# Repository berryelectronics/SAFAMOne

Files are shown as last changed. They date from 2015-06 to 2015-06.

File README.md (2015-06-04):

# SAFAM One | WORK IN PROGRESS
##[FORUM THREAD WITH UPDATES ETC](http://goo.gl/dDuPXW)
##A Simple and Fast Microcontroller
###Based on the STM32F103 Microcontroller
####And the STM32duino Core, build up by Roger Clark, mrburnette, Bobc, victor_pv and many more

This Dev Board is build up around the [STM32F103RET6, a 32-BIT ARM Cortex M3 Microcontroller by STMicroelectronics](http://www.st.com/web/en/resource/technical/document/datasheet/CD00191185.pdf)

It offers a full pinout of the chip with functions, aswell as multiple pinouts of the Serial Communication Pins (SPI, I2C, I2S, UART) aswell as a direct Port for 2.4" Touchscreens and 2.8" Touchscreens.
Also it comes with a break-away Black Magic Probe Clone.

As this Project is still WIP, the schematic and the board will change. 
When the project is finished and you decide to make your own, you're doing it at your own risk. But if the Magic Black Smoke comes up, please report it to me, so i can fix it :)

~Straw/Berryelectronics

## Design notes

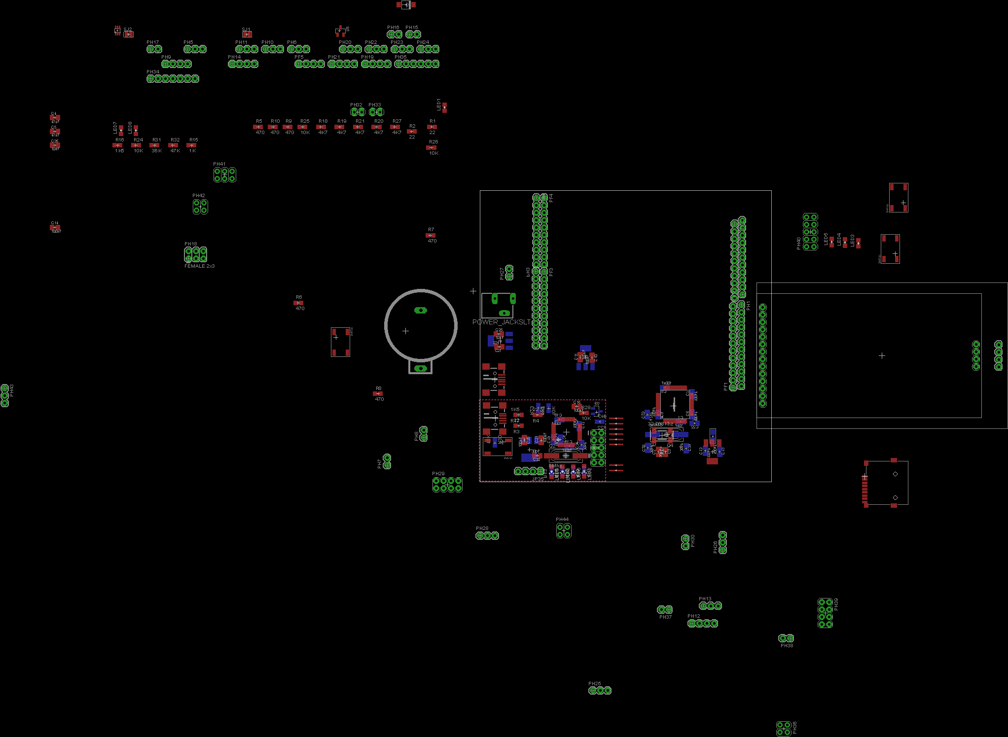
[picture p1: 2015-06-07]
Board_Design.png

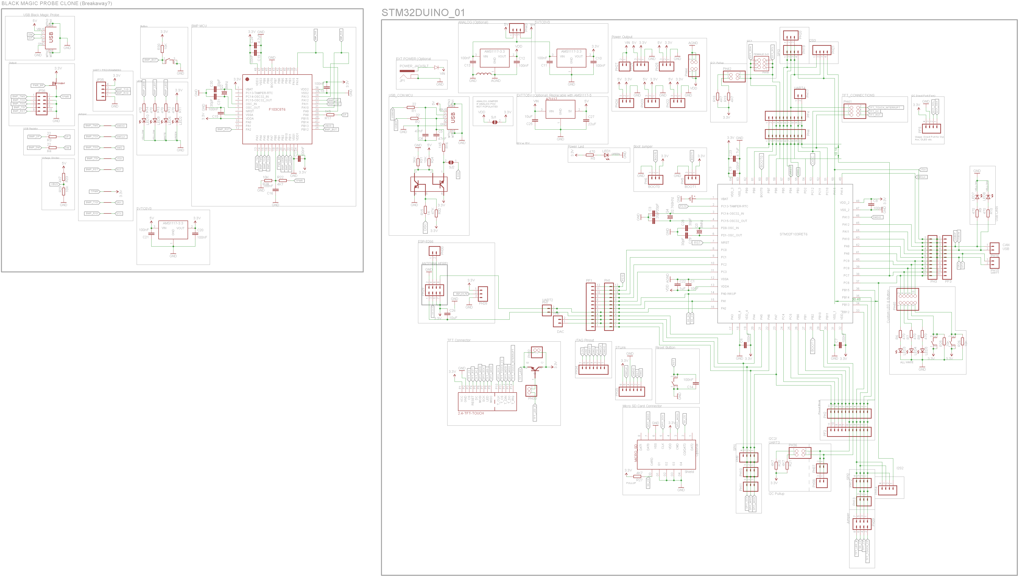
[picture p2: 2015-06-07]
Schematic.png

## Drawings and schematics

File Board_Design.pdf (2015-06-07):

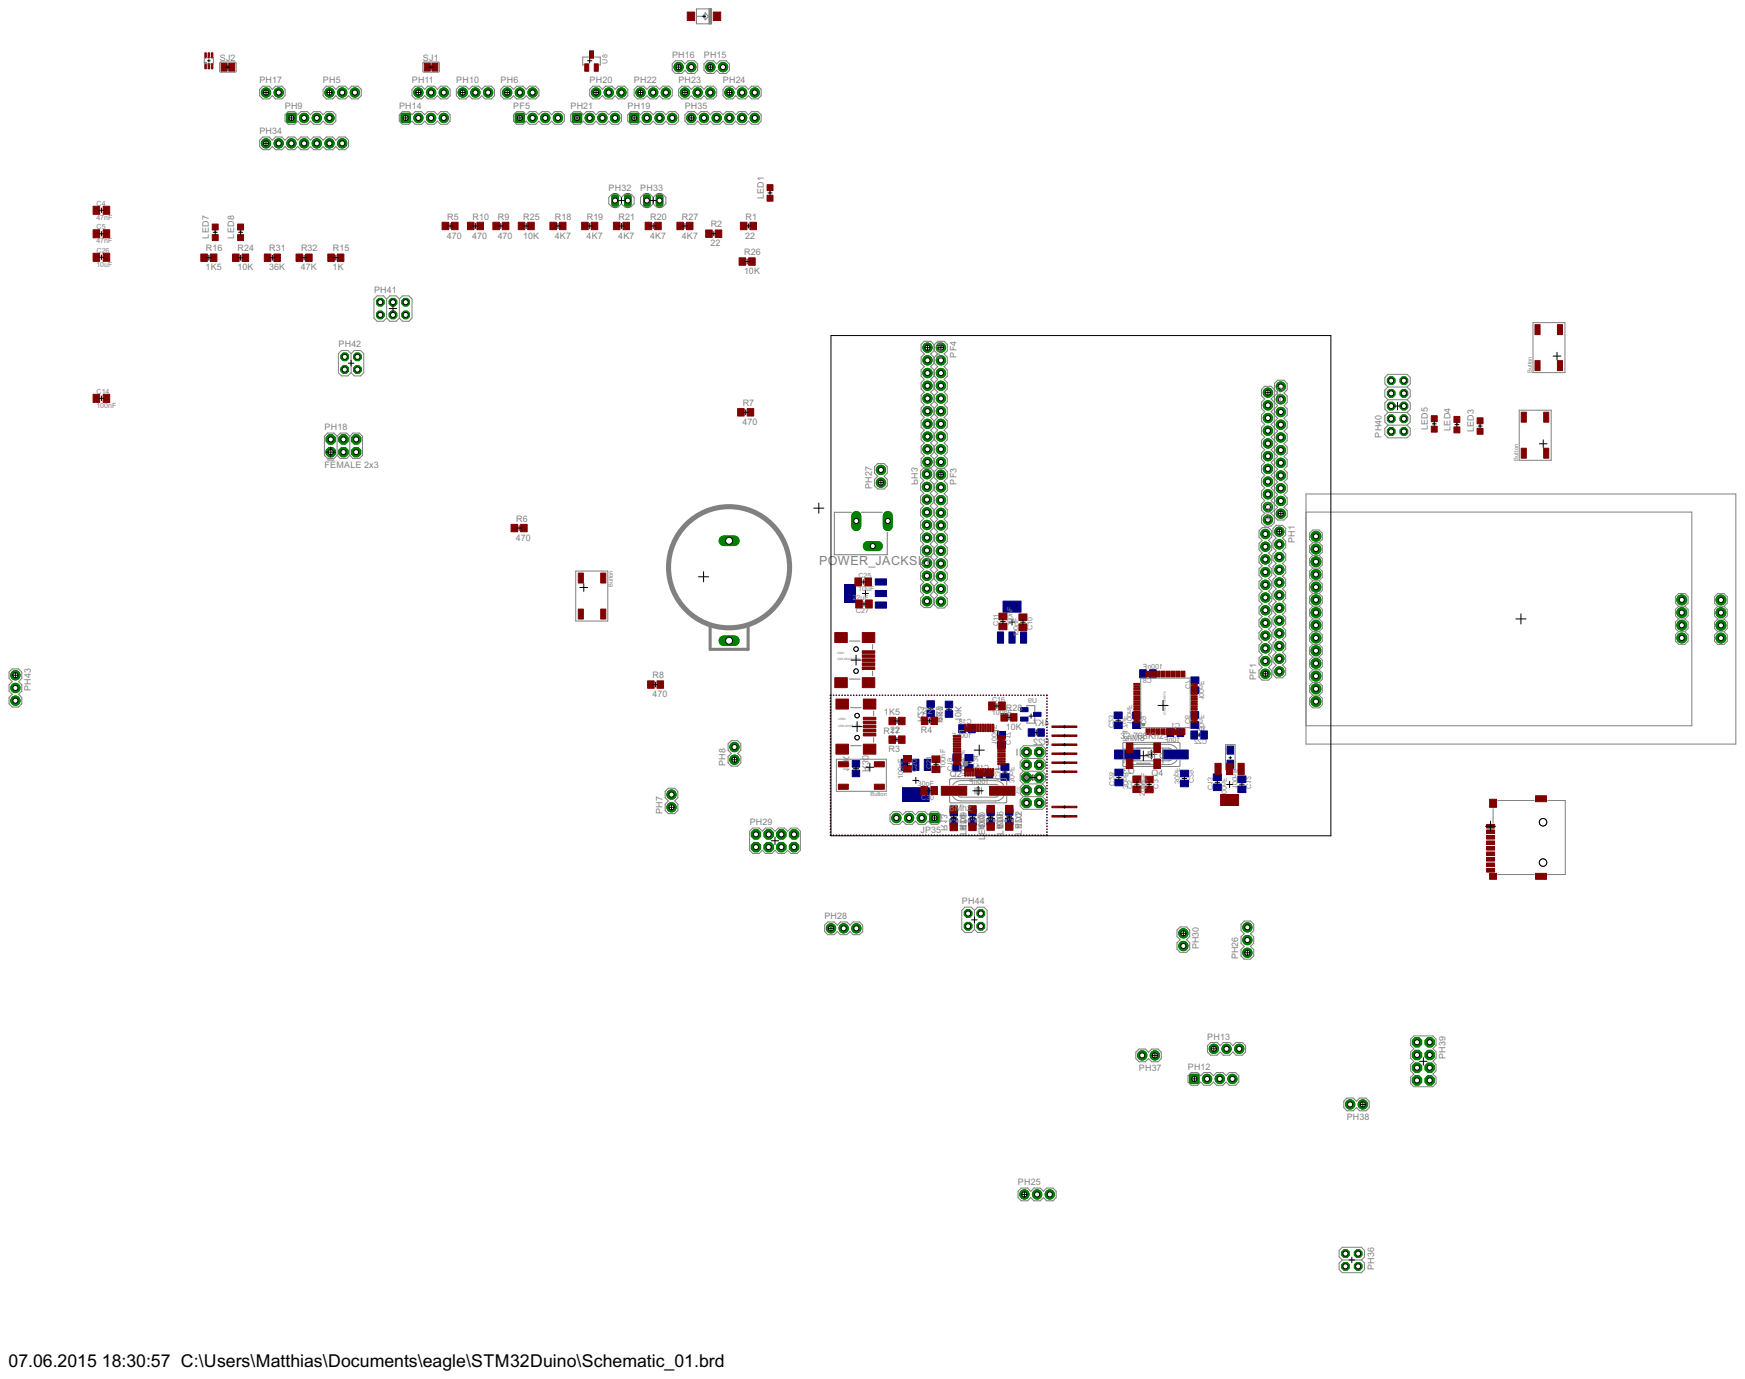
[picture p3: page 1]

07.06.2015 18:30:57 C:\Users\Matthias\Documents\eagle\STM32Duino\Schematic_01.brd

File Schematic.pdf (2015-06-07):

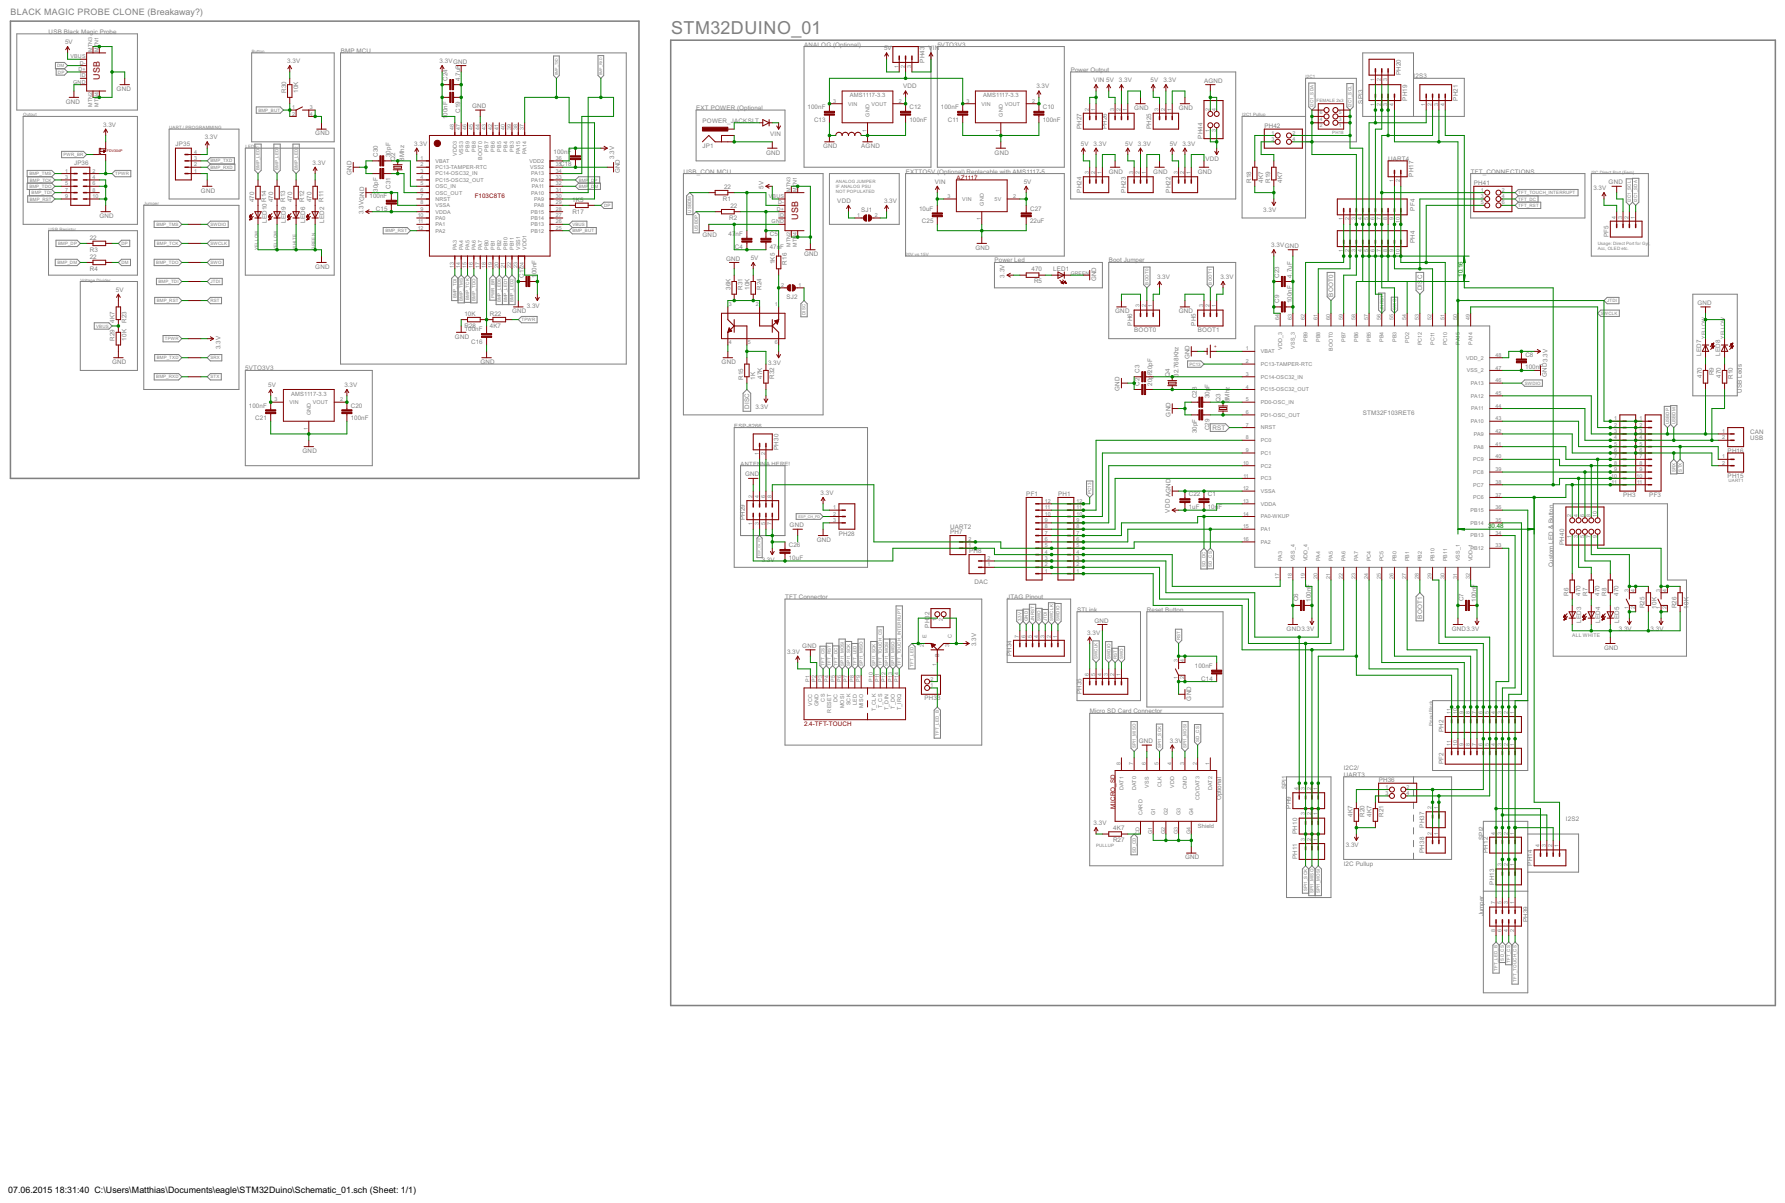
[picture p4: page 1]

BLACK MAGIC PROBE CLONE (Breakaway?)

USB Black Magic Probe

Usage: Direct Port for Gyr, Acc, OLED etc.

6 | 6 | 33 PB13

Micro SD Card Connector

07.06.2015 18:31:40 C:\Users\Matthias\Documents\eagle\STM32Duino\Schematic_01.sch (Sheet: 1/1)

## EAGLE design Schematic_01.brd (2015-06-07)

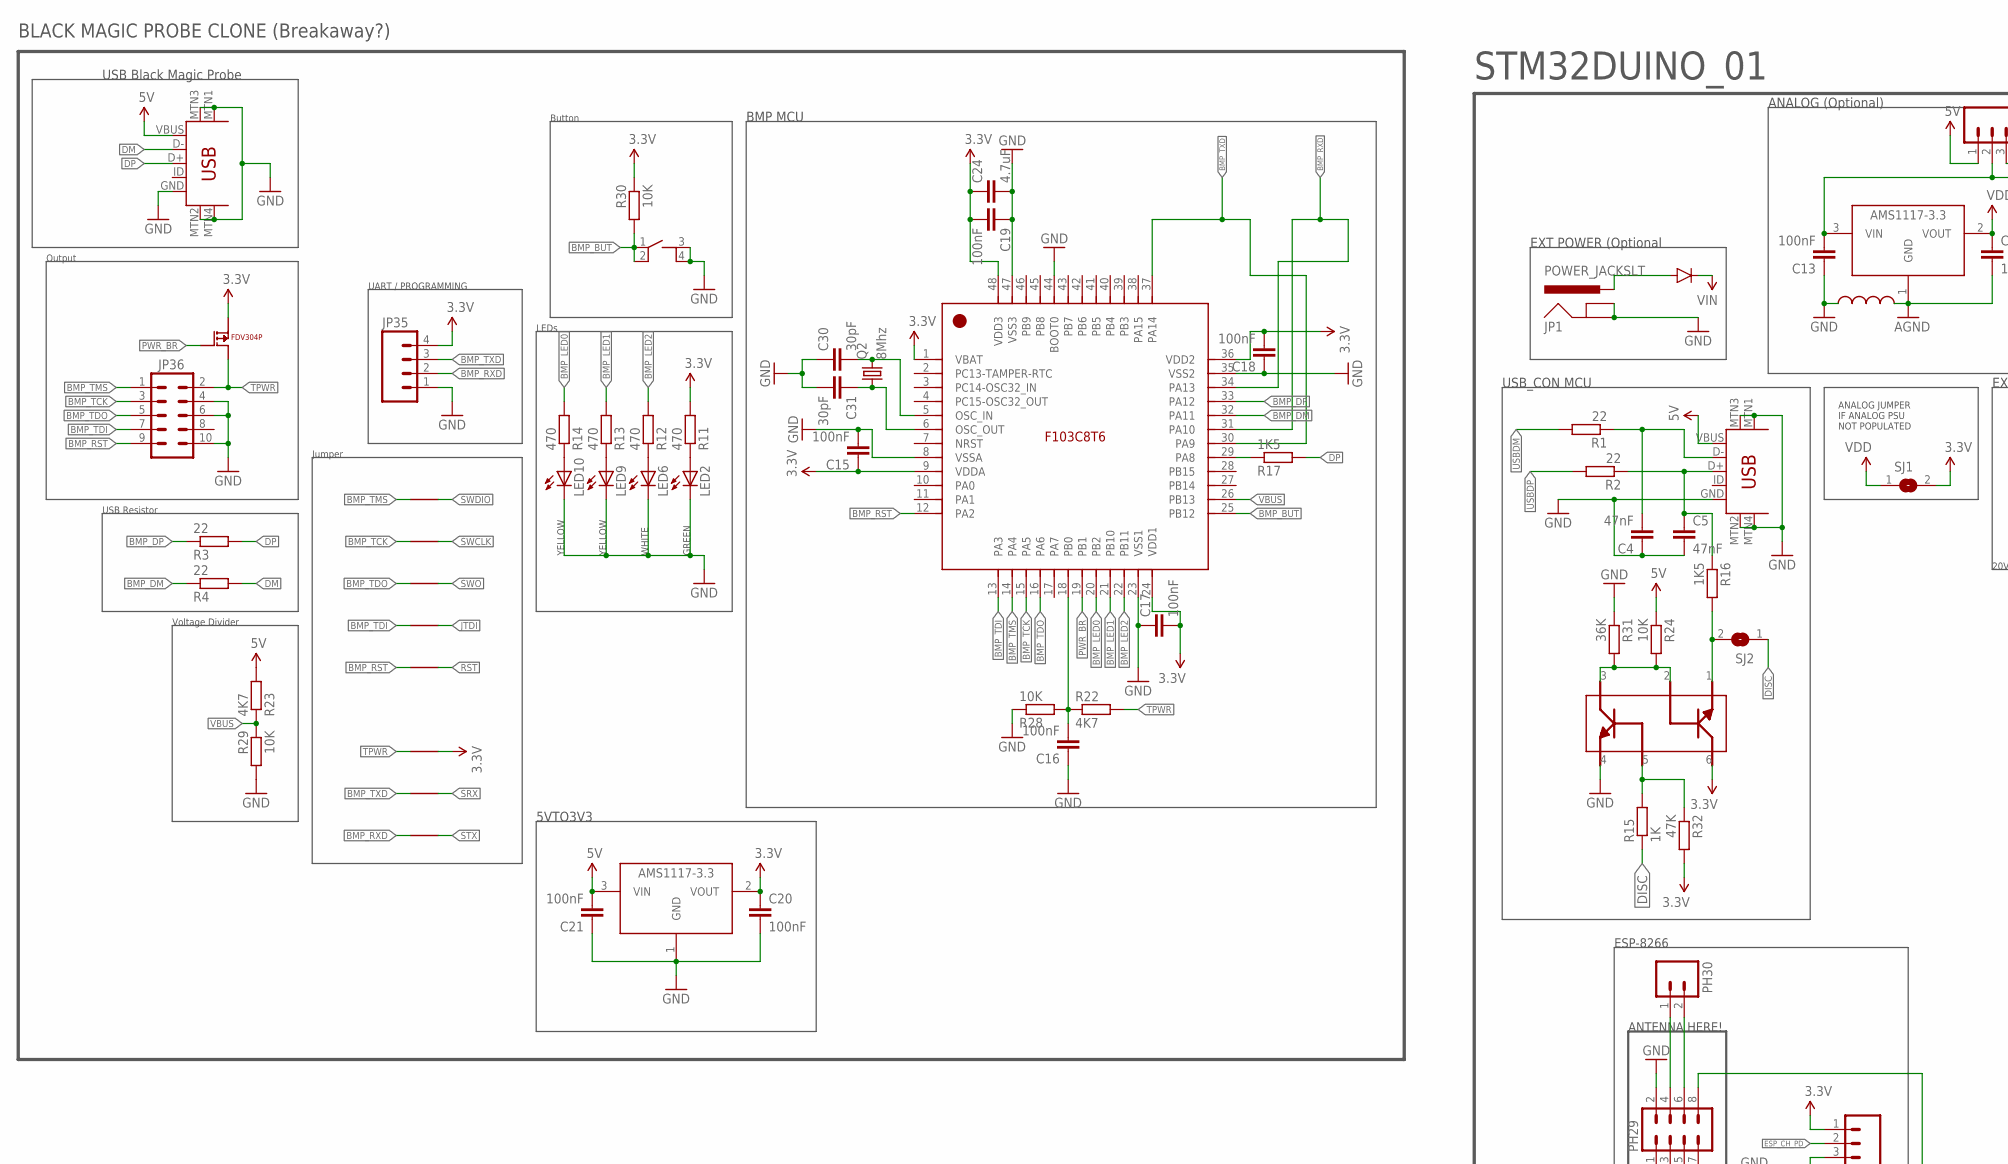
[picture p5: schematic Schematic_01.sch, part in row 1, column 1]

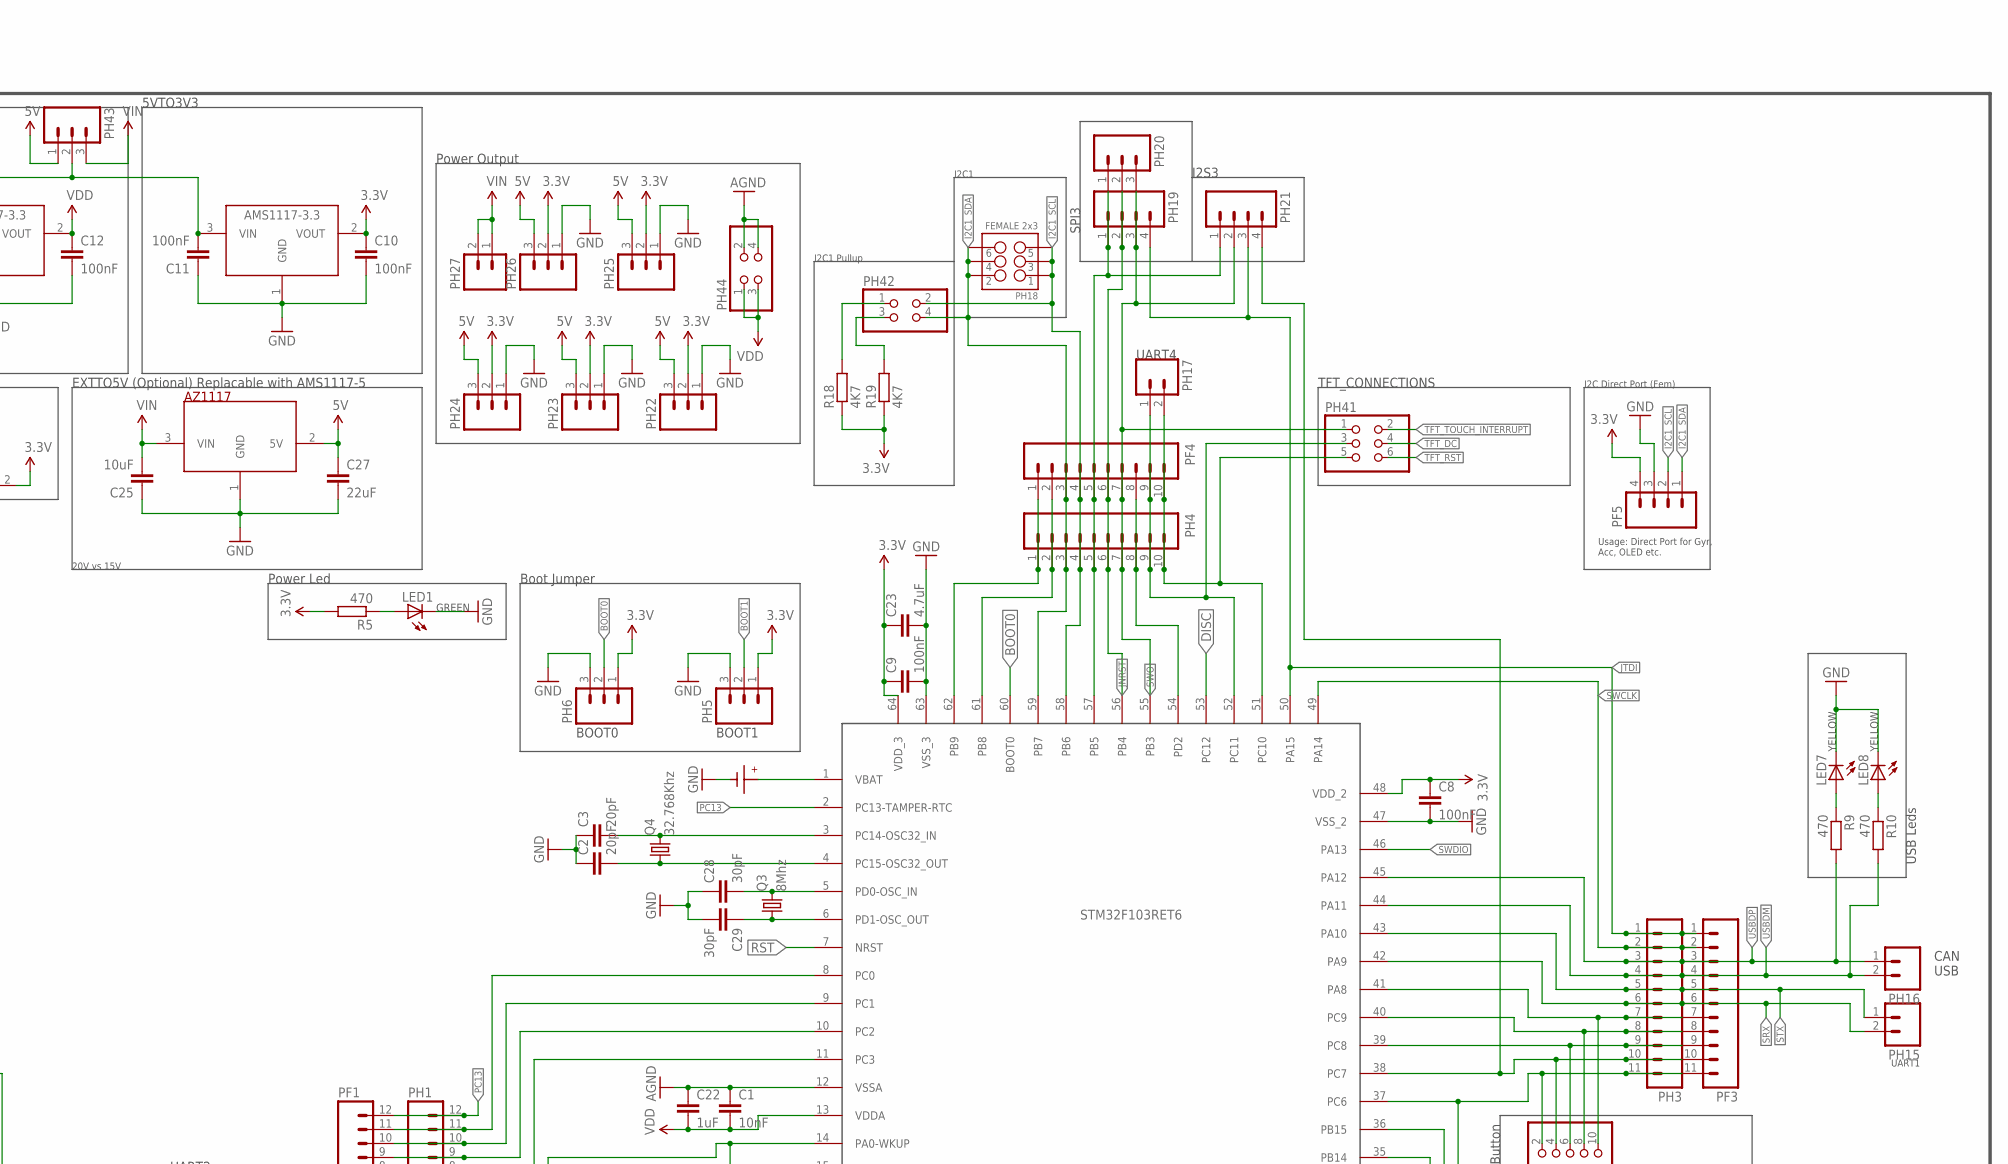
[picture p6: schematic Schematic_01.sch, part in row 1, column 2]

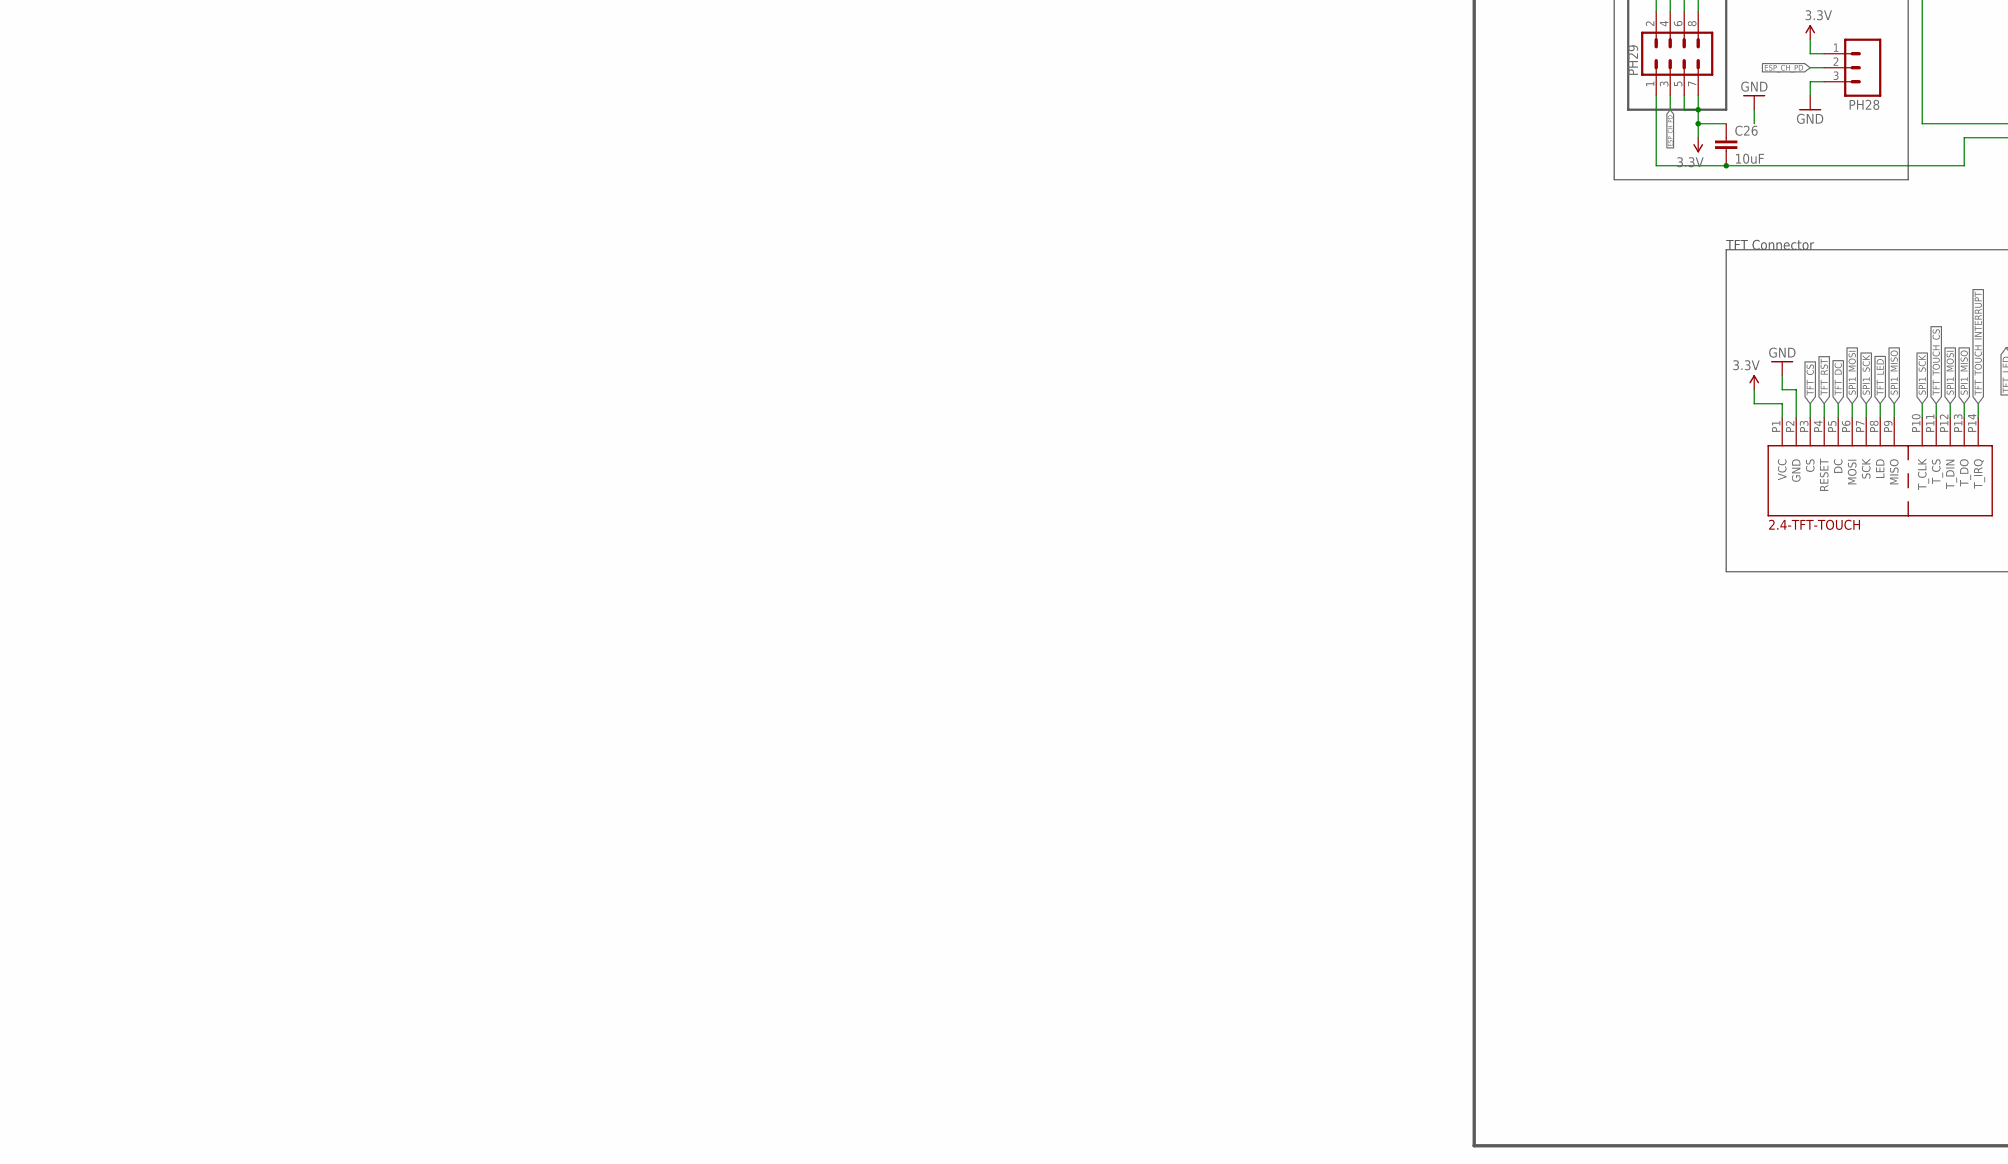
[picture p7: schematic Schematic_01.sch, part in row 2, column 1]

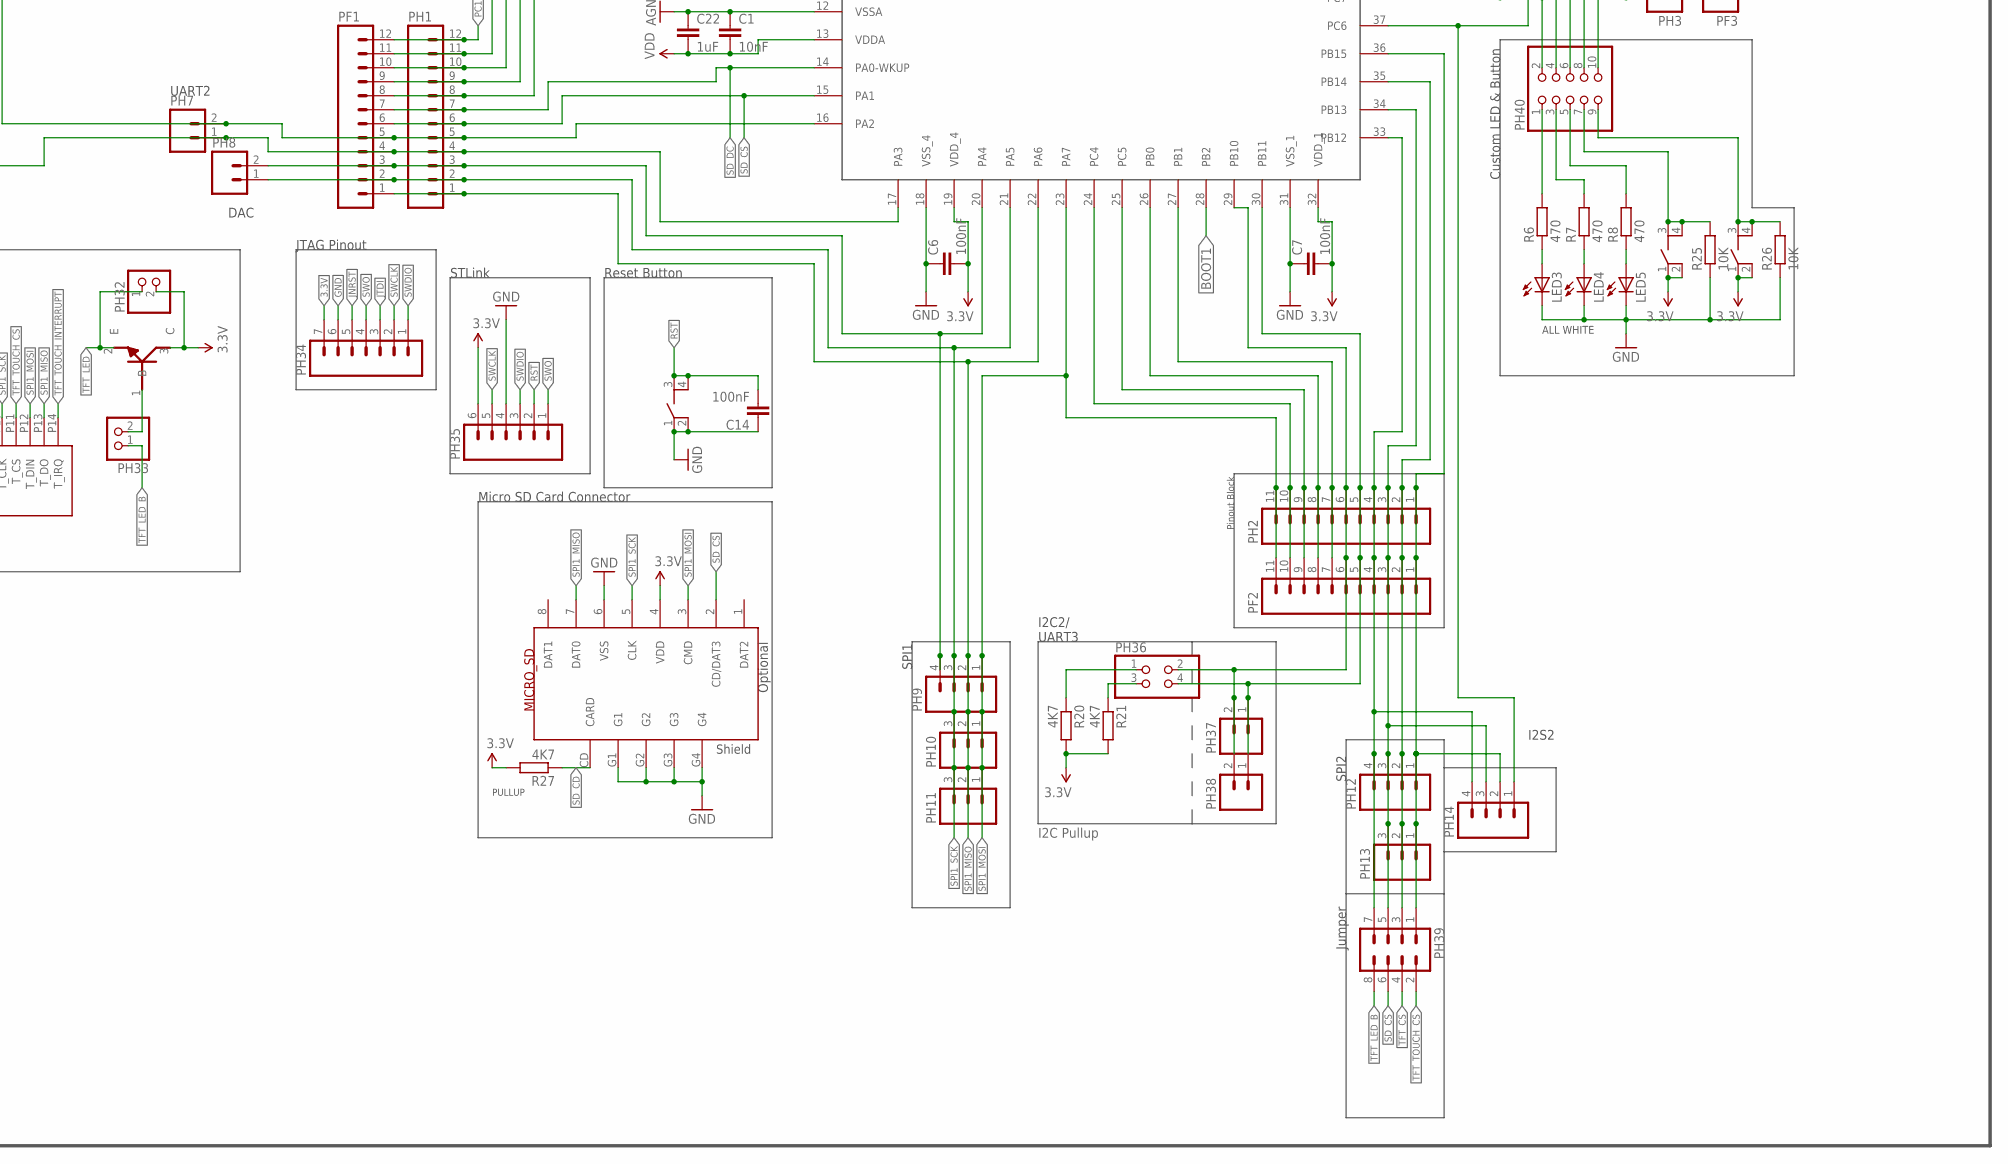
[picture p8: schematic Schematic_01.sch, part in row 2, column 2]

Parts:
C1: 10nF; C0805K
C2, C3: 20pF; C0805K
C4, C5: 47nF; C0805K
C6, C7, C8, C9, C10, C11, C12, C13, C14, C15, C16, C17, C18, C19, C20, C21: 100nF; C0805K
C22: 1uF; C0805K
C23, C24: 4.7uF; C0805K
C25, C26: 10uF; C0805K
C27: 22uF; C0805K
C28, C29, C30, C31: 30pF; C0805K
FB: SMD_FERRITE_BEAD; 0805
JP1: POWER_JACKSLT; POWER_JACK_SLOT
JP35: M04PTH; 1X04
JP36: M05X2PTH; AVR_ICSP
LED1, LED3, LED4, LED5, LED7, LED8: LEDCHIPLED_0805; CHIPLED_0805
LED2, LED6, LED9, LED10: LEDCHIPLED_1206; CHIPLED_1206
PF1: M12PTH; 1X12
PF2, PF3: M11PTH; 1X11
PF4: M10SILK_FEMALE_PTH; 1X10
PF5: M04PTH; 1X04
PH1: M12PTH; 1X12
PH2, PH3: M11PTH; 1X11
PH4: M10SILK_FEMALE_PTH; 1X10
PH5, PH6, PH10, PH11, PH13, PH20, PH22, PH23, PH24, PH25, PH26, PH28, PH43: M03PTH; 1X03
PH7, PH8, PH15, PH16, PH17, PH27, PH30, PH37, PH38: M02PTH; 1X02
PH9, PH12, PH14, PH19, PH21: M04PTH; 1X04
PH18: FEMALE 2x3; 2X3
PH29, PH39: M04X2; 2X4
PH31: TFT-TOUCH
PH32, PH33: PINHD-1X2; 1X02
PH34: M07; 1X07
PH35: M06SILK_FEMALE_PTH; 1X06
PH36, PH42, PH44: PINHD-2X2; 2X02
PH40: PINHD-2X5; 2X05
PH41: PINHD-2X3; 2X03
Q2, Q3: 8Mhz; SM49
Q4: 32.768Khz; MC-306
R1, R2, R3, R4: 22; R0805
R5, R6, R7, R8, R9, R10, R11, R12, R13, R14: 470; R0805
R15: 1K; R0805
R16, R17: 1K5; R0805
R18, R19, R20, R21, R22, R23, R27: 4K7; R0805
R24, R25, R26, R28, R29, R30: 10K; R0805
R31: 36K; R0805
R32: 47K; R0805
SJ1, SJ2: SJ
U1: STM32F103RET6; LQFP64_0.5MMPP
U2: STM32F103C8T6; LQFP48_7X7MM_0.5MMPP
U3, U4, U6: AMS1117-3.3; SOT223
U5: AZ1117-5.0; SOT223
U7: MBT3904DW1T1G; SOT236
U8: BC846A; SOT23-3
U9: FDV304P; SOT23-3
U$1, U$4, U$10, U$15, U$16, U$17, U$18, U$19: BRIDGE
U$2, U$5, U$8, U$9: SMD_BUT_6MM
U$6: CR2025_BATHOLDER_PTH; CR2025HOLDER_PTH
U$7: SD_CARD
U$25: 1N4007_SMD; DO-214AC
USB1, USB2: USB-MINIB-5PIN; USB-MINIB

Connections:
3.3V: C6.2, C7.2, C8.1, C9.1, C10.1, C15.1, C17.2, C18.2, C19.2, C20.1, C23.1, C24.1, C26.1, JP35.4, PF5.4, PH5.1, PH6.1, PH22.2, PH23.2, PH24.2, PH25.2, PH26.2, PH28.1, PH29.5, PH29.7, PH31.P1 (VCC), PH32.2, PH34.7, PH35.6, R5.2, R11.2, R18.1, R19.1, R20.2, R21.2, R27.2, R30.1, R32.2, SJ1.2, U1.19 (VDD_4), U1.32 (VDD_1), U1.48 (VDD_2), U1.64 (VDD_3), U2.1 (VBAT), U2.9 (VDDA), U2.24 (VDD1), U2.36 (VDD2), U2.48 (VDD3), U3.2 (VOUT), U6.2 (VOUT), U7.6, U8.3 (C), U9.2 (S), U$7.4 (VDD), U$8.1, U$8.2, U$9.1, U$9.2, U$10.P$2
5V: C21.2, C27.1, PH22.3, PH23.3, PH24.3, PH25.3, PH26.3, PH43.1, R23.2, R24.1, U5.2 (5V), U6.3 (VIN), USB1.VBUS, USB2.VBUS
AGND: C1.1, C12.2, C22.1, FB.P$4 (2), PH44.2, PH44.4, U1.12 (VSSA), U4.1 (GND)
BMP_BUT: R30.2, U2.25 (PB12), U$2.1, U$2.2
BMP_DM: R4.1, U2.32 (PA11)
BMP_DP: R3.1, U2.33 (PA12)
BMP_LED0: R14.2, U2.20 (PB2)
BMP_LED1: R13.2, U2.21 (PB10)
BMP_LED2: R12.2, U2.22 (PB11)
BMP_RST: JP36.9, U2.12 (PA2), U$15.P$1
BMP_RXD: JP35.2, U2.31 (PA10), U2.34 (PA13), U$1.P$1
BMP_TCK: JP36.3, U2.15 (PA5), U$18.P$1
BMP_TDI: JP36.7, U2.13 (PA3), U$16.P$1
BMP_TDO: JP36.5, U2.16 (PA6), U$17.P$1
BMP_TMS: JP36.1, U2.14 (PA4), U$19.P$1
BMP_TXD: JP35.3, U2.30 (PA9), U2.37 (PA14), U$4.P$1
BOOT0: PH6.2, U1.60 (BOOT0)
BOOT1: PH5.2, U1.28 (PB2)
DISC: R15.1, SJ2.1, U1.53 (PC12)
DM: R4.2, USB2.D-
DP: R3.2, R17.2, USB2.D+
ESP_CH_PD: PH28.2, PH29.3
GND: C2.1, C3.1, C4.1, C5.2, C6.1, C7.1, C8.2, C9.2, C10.2, C11.1, C13.1, C14.1, C15.2, C16.1, C17.1, C18.1, C19.1, C20.2, C21.1, C23.2, C24.2, C25.1, C27.2, C28.1, C29.2, C30.1, C31.2, FB.P$3 (1), JP1.GND@1 (GNDBREAK), JP1.GND@2 (GND), JP35.1, JP36.4, JP36.6, JP36.10, LED1.C, LED2.C, LED3.C, LED4.C, LED5.C, LED6.C, LED7.C, LED8.C, LED9.C, LED10.C, PF5.3, PH5.3, PH6.3, PH22.1, PH23.1, PH24.1, PH25.1, PH26.1, PH28.3, PH29.2, PH31.P2 (GND), PH34.6, PH35.4, R25.1, R26.1, R28.1, R29.2, R31.1, U1.18 (VSS_4), U1.31 (VSS_1), U1.47 (VSS_2), U1.63 (VSS_3), U2.8 (VSSA), U2.23 (VSS1), U2.35 (VSS2), U2.44 (BOOT0), U2.47 (VSS3), U3.1 (GND), U5.1 (GND), U6.1 (GND), U7.4, U$2.3, U$2.4, U$5.1, U$5.2, U$6.BATM, U$7.6 (VSS), U$7.G1, U$7.G2, U$7.G3, U$7.G4, USB1.GND, USB1.MTN1 (MTN2), USB1.MTN2 (MTN3), USB1.MTN3 (MTN1), USB1.MTN4, USB2.GND, USB2.MTN1 (MTN2), USB2.MTN2 (MTN3), USB2.MTN3 (MTN1), USB2.MTN4
I2C1_SCL: PF4.4, PF5.2, PH4.4, PH18.1, PH18.3, PH18.5, PH42.2, U1.58 (PB6)
I2C1_SDA: PF4.3, PF5.1, PH4.3, PH18.2, PH18.4, PH18.6, PH42.4, U1.59 (PB7)
JNRST: PF4.6, PH4.6, PH19.2, PH20.2, PH34.5, U1.56 (PB4)
JTDI: PF3.1, PH3.1, PH19.4, PH21.3, PH34.3, U1.50 (PA15), U$16.P$2
unnamed: LED10.A, R14.1
unnamed: R15.2, R32.1, U7.5
unnamed: PF1.11, PH1.11, U1.8 (PC0)
unnamed: C29.1, Q3.1, U1.6 (PD1-OSC_OUT)
unnamed: PF4.1, PH4.1, U1.62 (PB9)
unnamed: C3.2, Q4.4 (2), U1.3 (PC14-OSC32_IN)
unnamed: PF1.10, PH1.10, U1.9 (PC1)
unnamed: C2.2, Q4.1, U1.4 (PC15-OSC32_OUT)
unnamed: C28.2, Q3.2, U1.5 (PD0-OSC_IN)
unnamed: PF4.2, PH4.2, U1.61 (PB8)
unnamed: LED7.A, R9.1
unnamed: LED8.A, R10.1
unnamed: PF4.5, PH4.5, PH19.1, PH20.1, PH21.1, U1.57 (PB5)
unnamed: PF2.6, PH2.6, PH36.2, PH37.2, PH38.2, U1.29 (PB10)
unnamed: PH40.3, R7.2
unnamed: PF4.8, PH4.8, U1.54 (PD2)
unnamed: PH40.5, R8.2
unnamed: PH36.1, R20.1
unnamed: U1.1 (VBAT), U$6.BATP
unnamed: PH42.1, R18.2
unnamed: PH36.3, R21.1
unnamed: PH42.3, R19.2
unnamed: PF3.7, PH3.7, PH40.10, U1.41 (PA8)
unnamed: PF3.8, PH3.8, PH40.8, U1.40 (PC9)
unnamed: PH33.2, U8.1 (B)
unnamed: PF3.10, PH3.10, PH21.4, PH40.4, U1.38 (PC7)
unnamed: PF3.11, PH3.11, PH14.1, PH40.2, U1.37 (PC6)
unnamed: PF2.5, PH2.5, PH36.4, PH37.1, PH38.1, U1.30 (PB11)
unnamed: R24.2, R31.2, U7.2, U7.3
unnamed: PH29.4, PH30.1
unnamed: PH29.6, PH30.2
unnamed: LED1.A, R5.1
unnamed: PF2.7, PH2.7, U1.27 (PB1)
unnamed: PF2.8, PH2.8, U1.26 (PB0)
unnamed: PF2.9, PH2.9, U1.25 (PC5)
unnamed: PF2.10, PH2.10, U1.24 (PC4)
unnamed: R17.1, U2.29 (PA8)
unnamed: PF1.9, PH1.9, U1.10 (PC2)
unnamed: PF1.8, PH1.8, U1.11 (PC3)
unnamed: R16.2, SJ2.2, U7.1
unnamed: C30.2, Q2.2, U2.5 (OSC_IN)
unnamed: C31.1, Q2.1, U2.6 (OSC_OUT)
unnamed: C26.2, PF1.4, PH1.4, PH7.1, PH29.1, U1.17 (PA3)
unnamed: PF1.3, PH1.3, PH8.2, PH9.4, U1.20 (PA4)
unnamed: LED9.A, R13.1
unnamed: C16.2, R22.1, R28.2, U2.18 (PB0)
unnamed: LED6.A, R12.1
unnamed: LED2.A, R11.1
unnamed: C11.2, C13.2, PH43.2, U3.3 (VIN), U4.3 (VIN)
unnamed: PF3.9, PH3.9, PH40.6, U1.39 (PC8)
unnamed: C4.2, R1.1, USB1.D-
unnamed: PH40.1, R6.2
unnamed: JP1.PWR, U$25.ANODE
unnamed: LED3.A, R6.1
unnamed: LED4.A, R7.1
unnamed: LED5.A, R8.1
unnamed: C5.1, R2.1, R16.1, USB1.D+
unnamed: PH40.9, R26.2, U$9.3, U$9.4
unnamed: PH40.7, R25.2, U$8.3, U$8.4
unnamed: PF4.10, PH4.10, PH17.2, PH41.5, U1.51 (PC10)
unnamed: PF4.9, PH4.9, PH17.1, PH41.3, U1.52 (PC11)
unnamed: PF2.4, PH2.4, PH12.4, PH14.4, PH39.7, U1.33 (PB12)
unnamed: PF2.3, PH2.3, PH12.3, PH13.3, PH14.3, PH39.5, U1.34 (PB13)
unnamed: PF2.2, PH2.2, PH12.2, PH13.2, PH39.3, U1.35 (PB14)
unnamed: PF2.1, PH2.1, PH12.1, PH13.1, PH14.2, PH39.1, U1.36 (PB15)
P%1032: PF1.5, PH1.5, PH7.2, PH29.8, U1.16 (PA2)
PC13: PF1.12, PH1.12, U1.2 (PC13-TAMPER-RTC)
PWR_BR: U2.19 (PB1), U9.1 (G)
RST: C14.2, PH35.2, U1.7 (NRST), U$5.3, U$5.4, U$15.P$2
SD_CD: R27.1, U$7.CD (CARD)
SD_CS: PF1.6, PH1.6, PH39.6, U1.15 (PA1), U$7.2 (CD/DAT3)
SD_DC: PF1.7, PH1.7, U1.14 (PA0-WKUP)
SPI1_MISO: PF1.1, PH1.1, PH9.2, PH10.2, PH11.2, PH31.P9 (MISO), PH31.P13 (T_DO), U1.22 (PA6), U$7.7 (DAT0)
SPI1_MOSI: PF2.11, PH2.11, PH9.1, PH10.1, PH11.1, PH31.P6 (MOSI), PH31.P12 (T_DIN), U1.23 (PA7), U$7.3 (CMD)
SPI1_SCK: PF1.2, PH1.2, PH8.1, PH9.3, PH10.3, PH11.3, PH31.P7 (SCK), PH31.P10 (T_CLK), U1.21 (PA5), U$7.5 (CLK)
SRX: PF3.6, PH3.6, PH15.2, U1.42 (PA9), U$4.P$2
STX: PF3.5, PH3.5, PH15.1, U1.43 (PA10), U$1.P$2
SWCLK: PF3.2, PH3.2, PH34.2, PH35.5, U1.49 (PA14), U$18.P$2
SWDIO: PH34.1, PH35.3, U1.46 (PA13), U$19.P$2
SWO: PF4.7, PH4.7, PH19.3, PH20.3, PH21.2, PH34.4, PH35.1, PH41.1, U1.55 (PB3), U$17.P$2
TFT_CS: PH31.P3 (CS), PH39.4
TFT_DC: PH31.P5 (DC), PH41.4
TFT_LED: PH31.P8 (LED), PH32.1, U8.2 (E)
TFT_LED_B: PH33.1, PH39.8
TFT_RST: PH31.P4 (RESET), PH41.6
TFT_TOUCH_CS: PH31.P11 (T_CS), PH39.2
TFT_TOUCH_INTERRUPT: PH31.P14 (T_IRQ), PH41.2
TPWR: JP36.2, R22.2, U9.3 (D), U$10.P$1
USBDM: PF3.4, PH3.4, PH16.2, R1.2, R10.2, U1.44 (PA11)
USBDP: PF3.3, PH3.3, PH16.1, R2.2, R9.2, U1.45 (PA12)
VBUS: R23.1, R29.1, U2.26 (PB13)
VDD: C1.2, C12.1, C22.2, PH44.1, PH44.3, SJ1.1, U1.13 (VDDA), U4.2 (VOUT)
VIN: C25.2, PH27.1, PH27.2, PH43.3, U5.3 (VIN), U$25.CATHODE

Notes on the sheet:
DAC
UART2
BOOT1
BOOT0
Boot Jumper
Power Output
I2C2/ UART3
SPI1
UART4
CAN USB
SPI3
I2S3
SPI2
I2S2
Reset Button
USB Black Magic Probe
EXT POWER (Optional
5VTO3V3
EXTTO5V (Optional) Replacable with AMS1117-5
I2C Pullup
Shield
ANTENNA HERE!
ESP-8266
ANALOG (Optional)
Optional
ANALOG JUMPER IF ANALOG PSU NOT POPULATED
PULLUP
TFT Connector
Micro SD Card Connector
STLink
Jumper
Custom LED & Button
USB Leds
Power Led
TFT_CONNECTIONS
I2C Direct Port (Fem)
Usage: Direct Port for Gyr, Acc, OLED etc.
I2C1 Pullup
I2C1
Pinout Block

Board: 2 copper layers, 157 parts (33 on the bottom side), 120 nets, no tracks yet.

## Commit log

2015-06-04 Eagle Board Design
    [Schematic_01.brd, Schematic_01.sch]
2015-06-04 Added Schematic PDF and PNG
2015-06-07 Added a "Somewhat" of an Main Board Layout + PDF and PNG :)
    [Schematic_01.brd, Schematic_01.sch]

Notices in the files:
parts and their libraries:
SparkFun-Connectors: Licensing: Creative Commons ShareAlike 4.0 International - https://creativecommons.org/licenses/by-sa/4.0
